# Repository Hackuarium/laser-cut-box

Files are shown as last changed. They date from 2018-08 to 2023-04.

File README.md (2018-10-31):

## It's in the box

#### An OpenSCAD project to wrap your PCB in a box

Often we need to create custom boxes to wrap a printed circuit board (PCB) and this
may be time consuming.

In this project based on couple of parameters you can quickly and efficiently create DXF files that after laser cutting will provide the different elements to create the box. You may cut any number of holes (round or rectangle) on all the faces of the box and the coordinates will always be relative to the (0,0) that is the bottom left of the PCB.

Coordinates [x,y] of holes corresponds to the center.

You can render the box as a 3D image

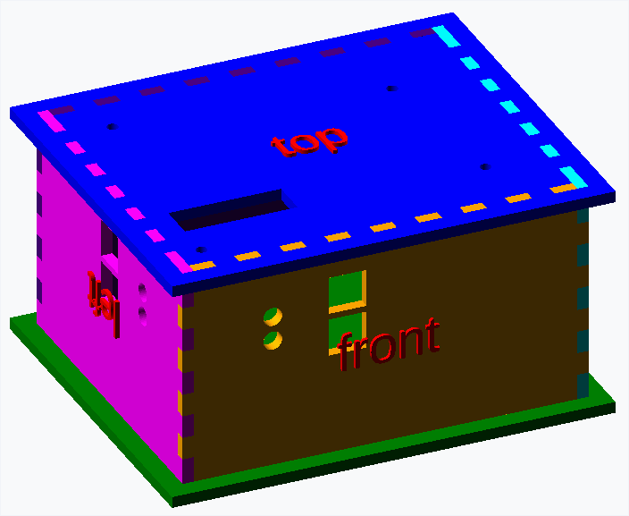
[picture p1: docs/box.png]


And you can also export easily as a SVG of DXF file for laser cutting.



## How to use it

Download OpenSCAD and open the file 'testBox.scad'.

The comments in the file should be clear enough to use this code.

## Exporting as DXF

You should change the following parameters before generating DXF:

- showLabels = false
- 3d = false

You may then render the image and export as DXF.

## Code example

```js
$fn=40;

use <pcbbox/pcb.scad>;

pcb(
    length=100,         // length of the PCB
    width=80,           // width of the PCB
    padding=1,          // space around the pcb (between pcb and box)
    thickness=3,        // thickness of the material to create the box
    pcbThickness=1.6,   // thickness of the box
    topToTop=20,        // distance from the top of the PCB to the external top of the box
    bottomToBottom=40,  // distance from the bottom of the PCB to the external bottom of the box
    extend=[10,10,0,0,0,0],          // should top and bottom 'extend' in order to assemble the box without glue
    screws=[            // position of holes to fix the PCB
        [5,5],
        [10,70],
        [85,15],
        [80,60]
    ],
    screwDiameter=3,    // diameter of the screws to fix the PCB
    topHoles=[          // holes to put on the top of the box
        [20,20,30,10]   // 0,0 is the bottom left of the PCB
    ],
    bottomHoles=[       // holes to put on the bottom of the box
        [40,40,10],     // array witlh 3 parameters = a circle [x,y,diameter]
        [20,20,5,5]     // array with 4 parameters = a rectangle [x,y,width,depth]
    ],
    frontHoles=[        // holes in front of the box, over the PCB
        [20, 2.5, 5],
        [40,5,10,10]
    ],
    frontHolesB=[       // holes in front of the box, under the PCB
        [20,2.5,5],
        [40,5,10,10]
    ],
    backHoles=[         // holes in the back of the box, over the PCB
        [20,2.5,5],
        [40,5,10,10]
    ],
    backHolesB=[        // holes in front of the box, under the PCB
        [20,2.5,5],
        [40,5,10,10]
    ],
    leftHoles=[         // holes on the left of the box, over the PCB
        [20,2.5,5],
        [40,5,10,10]
    ],
    leftHolesB=[        // holes on the left of the box, under the PCB
        [20,2.5,5],
        [40,5,10,10]
    ],
    rightHoles=[        // holes on the right of the box, over the PCB
        [20,2.5,5],
        [40,5,10,10]
    ],
    rightHolesB=[       // holes on the right of the box, under the PCB
        [20,2.5,5],
        [40,5,10,10]
    ],
    showLabels=true,    //should we show the labels
    labelsSize=10,      // size of the labels
    3d=true             // 3d rendering or just 2d ?
);
```

## Screwing the PCB

We recently often use black nylon M3 screw, standoff and spacer.

In order to fix the PCB we have the following sequence:

- M3 screw
- top of the case
- column standoff female spacer
- PCB
- column standoff male spacer
- bottom of the case
- M3 screw (we take 40 mm screws that we cut if needed)

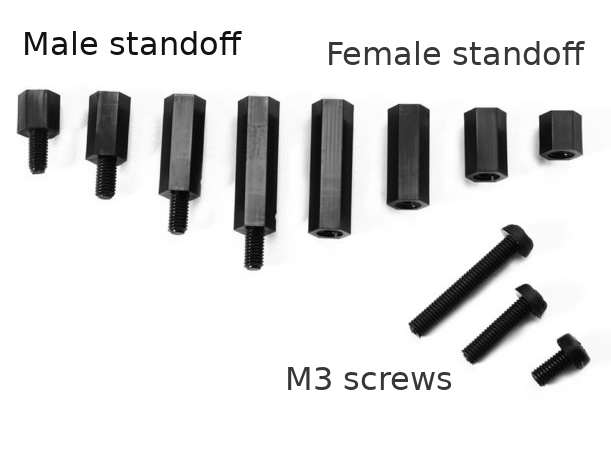
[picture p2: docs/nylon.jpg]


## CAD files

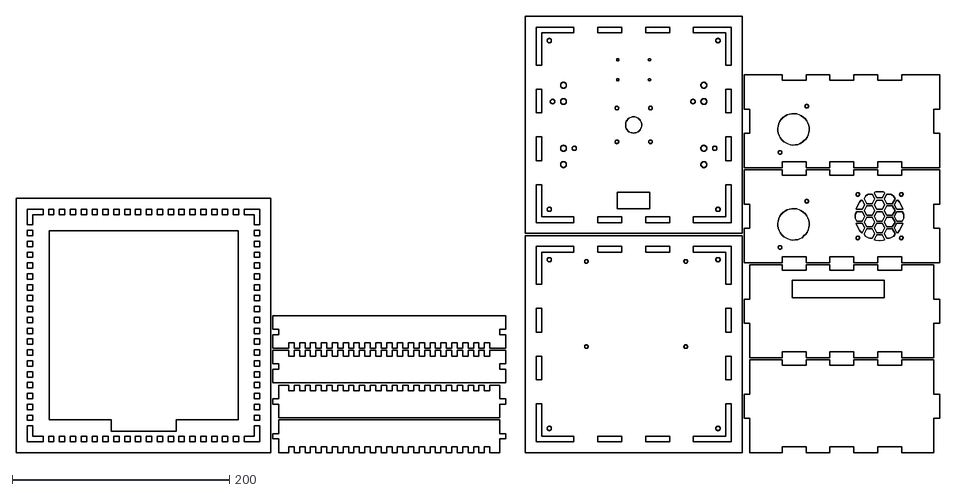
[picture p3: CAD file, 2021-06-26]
demo/bioreactor/bioreactor.dxf
849.2 x 401.2

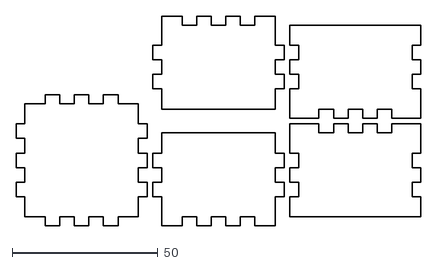
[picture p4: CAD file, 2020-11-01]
demo/box/box45x45x35.dxf
139.0 x 72.0

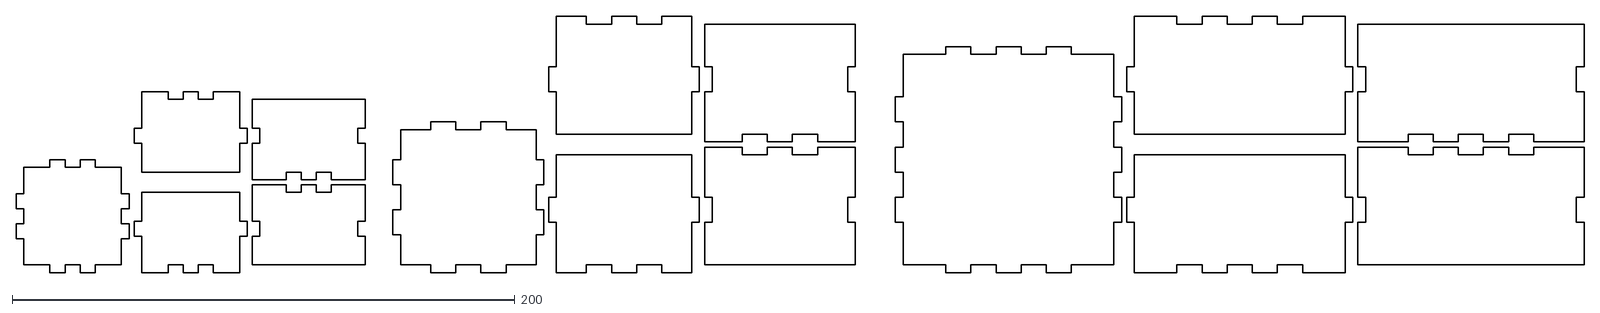
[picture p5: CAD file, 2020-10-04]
demo/box/many-openbox.dxf
624.0 x 102.0

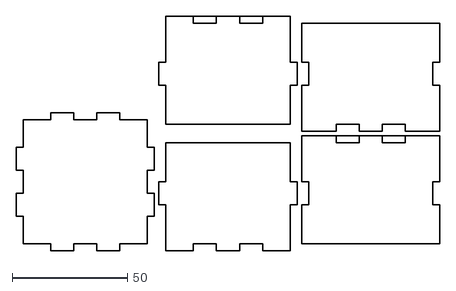
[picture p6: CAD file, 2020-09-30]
demo/box/box60x60x50.dxf
184.0 x 102.0

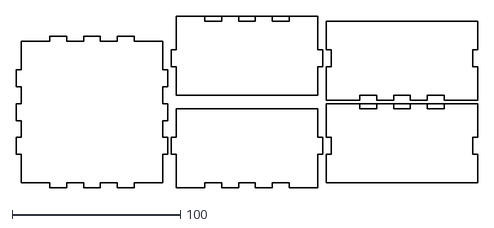
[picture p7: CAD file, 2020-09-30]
demo/box/box90x90x50.dxf
274.0 x 102.0

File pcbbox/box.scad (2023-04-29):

use <side.scad>;

module box(
    width=5,
    depth=5,
    height=5,
    thickness=1,
    fingerWidth=undef,
    labelsSize=10, 
    showLabels=true,
    labels=["Top","Bottom","Left","Right","Front","Back"],
    active=[1,1,1,1,1,1],
    3d=true,
    space=2,
    extends=[0,0,0,0,0,0],
    faceInsets=[0,0,0,0,0,0],
    holes=[[],[],[],[],[],[]]
    ) {
    fingerWidth = (fingerWidth==undef) ? thickness*2 : fingerWidth;
    
    assemble3d=[
        [
            [width/2, depth/2, height-thickness/2-faceInsets[0]], // top
            [0,0,0]
        ],[
            [width/2, depth/2, thickness/2+faceInsets[1]], // bottom
            [0,180,0]
        ],
        [
            [thickness/2+faceInsets[2], depth/2, height/2], // left
            [270,0,90]
        ],
        [
            [width-thickness/2-faceInsets[3], depth/2, height/2], // right
            [90,0,90]
        ],
        [
            [width/2, thickness/2+faceInsets[4], height/2], // front
            [90,0,0]
        ],
        [
            [width/2, depth-thickness/2-faceInsets[5], height/2], // back
            [270,0,0]
        ]
    ];
    
    extendsX=max(extends[0], extends[1]);

    assemble2d = (depth > (height * 2)) ?
        [
            [
                [width/2 + extendsX, depth*3/2+space + extends[0]*2 + extends[1], 0] // top
            ],
            [
                [width/2 + extendsX, depth/2 + extends[0], 0] // bottom
            ],
            [
                [width + depth/2 + extendsX*2 + space, height*5/2 + space*2, 0] // left
            ],
            [
                [width + depth/2 + extendsX*2 + space, height*7/2 + space*3, 0] // right
            ],
            [
                [width*3/2 + extendsX*2 + space, height/2, 0] // front
            ],
            [
                [width*3/2 + extendsX*2 + space, height*3/2 + space, 0] // back
            ]
        ] : 
        [
            [
                [width/2 + extends[0], depth*3/2+space + extends[0]*2 + extends[1], 0] // top
            ],
            [
                [width/2 + extends[0], depth/2 + extends[0], 0] // bottom
            ],
            [
                [width * 2 + depth / 2 + extends[0]*2 + space * 2, height/2, 0] // left
            ],
            [
                [width * 2 + depth / 2 + extends[0]*2 + space * 2, height*3/2 + space, 0] // right
            ],
            [
                [width*3/2 + extends[0]*2 + space, height/2, 0] // front
            ],
            [
                [width*3/2 + extends[0]*2 + space, height*3/2 + space, 0] // back
            ]
        ];

    


    assemble=(3d) ? assemble3d : assemble2d;
    
    // top
    if (active[0])
    translate(assemble[0][0])
        rotate(assemble[0][1])
            side(
                width, depth, thickness, fingerWidth,
                name="top", sideColor="blue", labelsSize=labelsSize, showLabels=showLabels,
                holes=holes[0], 3d=3d, extend=extends[0],
                holeShifts=[faceInsets[4],faceInsets[2],faceInsets[5],faceInsets[3]],
                male=[
                    specialFingers[0] ? specialFingers[0] : 1,
                    specialFingers[0] ? specialFingers[0] : 1,
                    specialFingers[0] ? specialFingers[0] : 1,
                    specialFingers[0] ? specialFingers[0] : 1,
                ]
            );

    // bottom
    if (active[1])
    translate(assemble[1][0])
        rotate(assemble[1][1])
            side(
                width, depth, thickness, fingerWidth,
                name="bottom", sideColor="green", labelsSize=labelsSize, showLabels=showLabels,
                holes=holes[1], 3d=3d, extend=extends[1],
                holeShifts=[faceInsets[4],faceInsets[3],faceInsets[5],faceInsets[2]],
                male=[
                    specialFingers[1] ? specialFingers[1] : 1,
                    specialFingers[1] ? specialFingers[1] : 1,
                    specialFingers[1] ? specialFingers[1] : 1,
                    specialFingers[1] ? specialFingers[1] : 1,
                ]
            );
    
    // left
    if (active[2])
    translate(assemble[2][0])
        rotate(assemble[2][1])
            side(
                depth, height, thickness, fingerWidth,
                name="left", sideColor="magenta", labelsSize=labelsSize, showLabels=showLabels,
                holes=holes[2], 3d=3d, extend=extends[2], textRotation=180,
                holeShifts=[faceInsets[0],faceInsets[4],faceInsets[1],faceInsets[5]],
                male=[
                    specialFingers[0] ? invertSpecialFinger(specialFingers[0]) : 0,
                    0,
                    specialFingers[1] ? invertSpecialFinger(specialFingers[1]) : 0,
                    0
                ]
            );

    // right
    if (active[3])
    translate(assemble[3][0])
        rotate(assemble[3][1])
            side(
                depth, height, thickness, fingerWidth,
                name="right", sideColor="cyan", labelsSize=labelsSize, showLabels=showLabels,
                holes=holes[3], 3d=3d, extend=extends[3],
                holeShifts=[faceInsets[1],faceInsets[4],faceInsets[0],faceInsets[5]],
                male=[
                    specialFingers[1] ? invertSpecialFinger(specialFingers[1]) : 0,
                    0,
                    specialFingers[0] ? invertSpecialFinger(specialFingers[0]) : 0,
                    0
                ]
            );

    // front
    if (active[4])
    translate(assemble[4][0])
        rotate(assemble[4][1])
            side(
                width, height, thickness, fingerWidth,
                name="front", sideColor="orange", labelsSize=labelsSize, showLabels=showLabels,
                holes=holes[4], 3d=3d, extend=extends[4],
                holeShifts=[faceInsets[1],faceInsets[2],faceInsets[0],faceInsets[3]],
                male=[
                    specialFingers[1] ? invertSpecialFinger(specialFingers[1]) : 0,
                    1,
                    specialFingers[0] ? invertSpecialFinger(specialFingers[0]) : 0,
                    1
                ]
            );
    
    // back
    if (active[5])
    translate(assemble[5][0])
        rotate(assemble[5][1])
            side(
                width, height, thickness, fingerWidth,  
                name="back", sideColor="indigo", labelsSize=labelsSize, showLabels=showLabels,
                holes=holes[5], 3d=3d, extend=extends[5], textRotation=180,
                holeShifts=[faceInsets[0],faceInsets[2],faceInsets[1],faceInsets[3]],
                male=[
                    specialFingers[0] ? invertSpecialFinger(specialFingers[0]) : 0,
                    1,
                    specialFingers[1] ? invertSpecialFinger(specialFingers[1]) : 0,
                    1
                ]
            );
};


function invertSpecialFinger(value) = (value==1) ? 0 : (value==0) ? 1 : (value==2) ? 3 : (value==3) ? 2 : undef;

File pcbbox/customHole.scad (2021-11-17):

use <side.scad>;

module customHole(kind, parameters) {
    if (kind=="Custom") {
        echo("Custom hole was not implemented");
    } else if (kind=="Nema17") {
        circle(d=15);
        translate([31/2,31/2]) circle(d=3.3);
        translate([-31/2,31/2]) circle(d=3.3);
        translate([31/2,-31/2]) circle(d=3.3);
        translate([-31/2,-31/2]) circle(d=3.3);
    } else if (kind=="Nema23") {
        circle(d=11);
        translate([47.14/2,47.14/2]) circle(d=3.3);
        translate([-47.14/2,47.14/2]) circle(d=3.3);
        translate([47.14/2,-47.14/2]) circle(d=3.3);
        translate([-47.14/2,-47.14/2]) circle(d=3.3);
    } else if (kind=="RectangularHoles") {
        width=parameters[0];
        height=parameters[1];
        diamter=parameters[2];
        translate([width/2,height/2]) circle(d=diameter);
        translate([-width/2,height/2]) circle(d=diameter);
        translate([width/2,-height/2]) circle(d=diameter);
        translate([-width/2,-height/2]) circle(d=diameter);
    } else if (kind=="Grid") {
        width=parameters[0];
        height=parameters[1];
        number=parameters[2];
        wall=parameters[3]; // thickness to keep

        removeWidth=(width-(number-1)*wall)/number;
        removeHeight=(width-(number-1)*wall)/number;

        difference() {
            square([width,height], center=true);
            difference() {
                square([width,height], center=true);
                translate([-width/2, -height/2])
                for (i = [0:number]) {
                        translate([i * (removeWidth + wall), 0, 0])
                        for (i = [0:number]) {
                            translate([0, i * (removeWidth + wall), 0])
                            square([removeWidth,removeHeight]);
                    }
                }
            }
        }
    } else if (kind=="Fan60") {
        diameter=7;
        distance=10;

        difference() {
            circle(d=55);
            difference() {
                circle(d=55);
                for (i = [0:10]) {
                        translate([i * distance, -25, 0])
                        for (i = [0:10]) {
                            translate([-25, i * distance, 0])
                            circle(d=diameter);
                    }
                }
            }
        }
       
        translate([25,25]) circle(d=3.3);
        translate([-25,25]) circle(d=3.3);
        translate([25,-25]) circle(d=3.3);
        translate([-25,-25]) circle(d=3.3);
    } else if (kind=="Fan50") {
        diameter=10;
	gap=2;
	deltaV=(sin(60)*diameter+gap)/2;
	deltaH=cos(30)*deltaV*4;

        difference() {
            circle(d=45);
            difference() {
                circle(d=46);
		translate([-deltaH*3,-21.5,0]) {
             	   for (i = [0:10]) {
                            translate([0, i * deltaV, 0])
                        for (j = [0:10]) {
                        	translate([(i%2) * deltaH / 2 + deltaH * j, 0, 0])
			    circle(d=diameter,$fn=6);
   	                }
   	           }
	 	}
            }
        }
       
        translate([20,20]) circle(d=3.3);
        translate([-20,20]) circle(d=3.3);
        translate([20,-20]) circle(d=3.3);
        translate([-20,-20]) circle(d=3.3);
    } else if (kind=="hexagon") {
	diameter=10;
        width=80;
        height=60;
	gap=2;
	deltaV=(sin(60)*diameter+gap)/2;
	deltaH=cos(30)*deltaV*4;

        difference() {
	    square([width,height], center=true);
            difference() {
	    	square([width,height], center=true);
		translate([-deltaH*3,-21.5,0]) {
             	   for (i = [0:10]) {
                            translate([0, i * deltaV, 0])
                        for (j = [0:10]) {
                        	translate([(i%2) * deltaH / 2 + deltaH * j, 0, 0])
			    circle(d=diameter,$fn=6);
   	                }
   	           }
	 	}
            }
        }
       
        translate([20,20]) circle(d=3.3);
        translate([-20,20]) circle(d=3.3);
        translate([20,-20]) circle(d=3.3);
        translate([-20,-20]) circle(d=3.3);
    } else if (kind=="Peristaltic") {
        rotation=parameters[0];
        interHole=49;
        rotate(rotation) {
            circle(d=29);
            translate([-interHole/2,0]) circle(d=3.3);
            translate([interHole/2,0]) circle(d=3.3);
        }
    } else if (kind=="LoadingCell") {
        rotation=parameters[0];
        width=16;
        total=83;
        hole=55;
        rotate(a=rotation) {
            translate([-total/2,-width/2]) {
                // square([hole,width]);
                translate([hole+8,width/2]) circle(d=5.4);
                translate([hole+23,width/2]) circle(d=5.4);
                translate([hole+8,width/2+10]) circle(d=4);
            }
        }
    } else if (kind=="Insert") {
        side(
            width=parameters[0],
            height=parameters[1],
            thickness=parameters[2],
            fingerWidth=parameters[3],
            color="Cyan"
        );
    } else if (kind=="InsertFilled") {
        difference() {
            side(
                width=parameters[0],
                height=parameters[1],
                thickness=parameters[2],
                fingerWidth=parameters[3],
                color="Cyan"
            );
            square([parameters[0]-2*parameters[2]+0.001, parameters[1]-2*parameters[2]+0.001],true);
        }
        
    }
}

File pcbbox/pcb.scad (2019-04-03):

use <box.scad>;

module pcb(
    length=100,
    width=80,
    padding=1, // space around the pcb
    thickness=3, // thickness of the material
    pcbThickness=1.6,
    topToTop=20, // distance from the top of the PCB to the top of the box
    bottomToBottom=20, // distance from the bottom of the PCB to the bottom of the box,
    screws=[],
    screwDiameter=3,
    frontHoles=[],
    frontHolesB=[],
    backHoles=[],
    backHolesB=[],
    leftHoles=[],
    leftHolesB=[],
    rightHoles=[],
    rightHolesB=[],
    topHoles=[],
    bottomHoles=[],
    labelsSize=10,
    extend=0,
    showLabels=false,
    show="",
    3d=false,
    fingerWidth=undef,
    specialFingers=[],
    active=[1,1,1,1,1,1]
) {

    box(
        width=length+padding*2+thickness*2,
        depth=width+padding*2+thickness*2,
        height=pcbThickness+topToTop+bottomToBottom,
        thickness=thickness,
        fingerWidth=fingerWidth,
        labelsSize=labelsSize, 
        showLabels=showLabels,
        labels=["Top","Bottom","Left","Right","Front","Back"],
        active=active,
        specialFingers=specialFingers,
        3d=3d,
        space=2,
        extends=[extend,extend,0,0,0,0],
        holes=[
            concat ( // top
                [for(hole = topHoles)
                    concat([hole.x+padding, hole.y+padding],[for (i=[2:1:len(hole)-1]) hole[i]])
                ],
                [for(screw = screws)
                    [screw.x+padding, screw.y+padding, screwDiameter]
                ]
            ),
            concat ( // bottom
                [for(hole = bottomHoles)
                    concat([length-hole.x+padding, hole.y+padding],[for (i=[2:1:len(hole)-1]) hole[i]])
                ],
                [for(screw = screws)
                    [length-screw.x+padding, screw.y+padding, screwDiameter]
                ]
            ),
            concat ( // left
                [for(hole = leftHoles)
                    concat([hole.x+padding, topToTop-hole.y-thickness],[for (i=[2:1:len(hole)-1]) hole[i]])
                ],
                [for(hole = leftHolesB)
                    concat([hole.x+padding, pcbThickness+topToTop+hole.y-thickness],[for (i=[2:1:len(hole)-1]) hole[i]])
                ]
            ),
            concat ( // right
                [for(hole = rightHoles)
                    concat([hole.x+padding, pcbThickness+bottomToBottom+hole.y-thickness],[for (i=[2:1:len(hole)-1]) hole[i]])
                ],
                [for(hole = rightHolesB)
                    concat([hole.x+padding, bottomToBottom-hole.y-thickness],[for (i=[2:1:len(hole)-1]) hole[i]])
                ]
            ),
            concat ( // front
                [for(hole = frontHoles)
                    concat([hole.x+padding, pcbThickness+bottomToBottom+hole.y-thickness],[for (i=[2:1:len(hole)-1]) hole[i]])
                ],
                [for(hole = frontHolesB)
                    concat([hole.x+padding, bottomToBottom-hole.y-thickness],[for (i=[2:1:len(hole)-1]) hole[i]])
                ]
            ),
            concat ( // back
                [for(hole = backHoles)
                    concat([hole.x+padding, topToTop-hole.y-thickness],[for (i=[2:1:len(hole)-1]) hole[i]])
                ],
                [for(hole = backHolesB)
                    concat([hole.x+padding, pcbThickness+topToTop+hole.y-thickness],[for (i=[2:1:len(hole)-1]) hole[i]])
                ]
            )
        ]
    );
}

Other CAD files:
pcbbox/side.scad
demo/bioreactor.scad
demo/bioreactor/bioreactor.scad
demo/box.scad
demo/box/bigbox.scad
demo/box/box.scad
demo/box/many-openbox copy.scad
demo/esp12e.scad
demo/esp32-rgb.scad
demo/i2c-screen/i2c-screen.scad
demo/incubator/incubator.scad
demo/many-openbox.scad
demo/openbox.scad
demo/pcb3dPrinting.scad
demo/shelf/box.scad
demo/shelf/cases.scad
demo/spectro-through.scad
demo/spectro.scad
demo/spectro/spectro-through.scad
demo/spectro/spectro.scad
testBox.scad
testPcb.scad

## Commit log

2018-08-04 add 3d example and demo folder
    [box.scad, pcb.scad, pcb3dPrinting.scad]
2018-09-16 fix rectangular side holes orientation
    [box.scad, pcb.scad, side.scad]
2018-09-16 improve code for spectro box0
    [box.scad, customHole.scad, pcb.scad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]
2018-09-16 improve demo files
    [pcb.scad, spectro.scad]
2018-09-19 fix relative parameters for 3d
    [spectro.scad]
2018-09-19 remove front hole of cell
    [spectro.scad]
2018-09-23 fix extendsX if only bottom
    [box.scad]
2018-09-23 deal correctly with sides clockwise
    [side.scad]
2018-09-27 improve spectro
    [pcb.scad, spectro.scad]
2018-09-27 try cubePuzzle
    [cubePuzzle.scad]
2019-03-23 change hole for spectro
    [customHole.scad, spectro-through-304.dxf, spectro-through.scad]
2019-04-03 remove cube puzzle
    [box.scad, cubePuzzle.scad, pcb.scad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]
2019-04-03 improve documentation
    [box.scad, customHole.scad, pcb.scad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]
2019-05-05 add esp12e
    [esp12e.scad]
2019-05-06 update esp12e box
    [esp12e.scad]
2019-05-07 fix comment in spectro
    [spectro.scad]
2019-12-01 feat: add box for esp32-rgb
    [esp32-rgb.scad]
2020-02-15 center the holes
    [spectro-through.scad]
2020-08-22 feat: add bioreactor and new hole types
    [bioreactor.scad, customHole.scad]
2020-08-22 feat: add more customHoles and improve bioreactor demo
    [bioreactor.scad, customHole.scad]
2020-08-30 close https://github.com/Hackuarium/bioreactor/issues/40
    [bioreactor.scad, customHole.scad]
2020-08-30 fix: increase hole of stepper
    [customHole.scad]
2020-09-07 chore: fix bottom
    [customHole.scad]
2020-09-13 feat: add top of bioreactor
    [bioreactor.scad]
2020-09-26 feat: add hole for power in bioreactor
    [bioreactor.scad, customHole.scad]
2020-09-27 feat: add holes for loading cell cables
    [bioreactor.scad, customHole.scad]
2020-09-30 feat: add open box example
    [box60x60.dxf, box90x90.dxf, openbox.scad]
2020-10-04 feat: add example of many open boxes
    [many-openbox.dxf, many-openbox.scad, side.scad]
2020-10-04 feat: increase bioreactor fan size
    [bioreactor.scad, customHole.scad]
2020-10-17 fix(bioreactor): add 4 loading cells
    [bioreactor.scad, customHole.scad]
2020-10-18 fix: loading cell hole
    [customHole.scad]
2020-10-18 fix: peristaltic pump orientation in bioreactor
    [bioreactor.scad]
2020-11-01 fix: sides holes of bioreactor and pcb for loading cell
    [bioreactor.scad]
2020-11-01 chore: demo of small boxes update
    [box45x45x35.dxf, box60x60x50.dxf, box90x90x50.dxf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]
2021-03-28 fix: holes for peristaltic pumps
    [bioreactor.scad]
2021-06-26 feat: hexagonal holes for fan
    [bioreactor.dxf, customHole.scad, openbox.scad]
2021-06-26 chore: update bioreactor.dxf
    [bioreactor.dxf]
2021-11-17 refactor: add some folders
    [bioreactor.dxf, bioreactor.scad, box.scad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]
2021-11-17 feat: add incubator boxes
    [customHole.scad, i2c-screen.scad, incubator.scad]
2023-04-29 chore: adding more examples
    [bigbox.scad, box.scad, cases.scad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]
